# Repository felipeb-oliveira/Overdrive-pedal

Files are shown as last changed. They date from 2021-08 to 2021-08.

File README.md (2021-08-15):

# Overdrive-pedal

## About
A simple overdrive circuit implemented with a OpAmp with soft clipping and a tone control. The OpAmp is configured as a non-inverting amplifier supplied with +9V and GND, with a 4.5V DC bias. The circuit is separated in 5 stages (see schematic image below the 3D model):
  1. Input: one Mono jack for audio;
  2. Equalization: capacitors to filter out some low noise and DC;
  3. Gain stage with soft clipping (made by the 2 opposed diodes on the OpAmp feedback) and low pass filter (capacitor on the OpAmp feedback, and grounded capacitor and resistor on the OpAmp negative input);
  4. Tone Control (Inpired by the Big Muff tone control circuit): basicaly a low pass filter in parallel with a high pass filter, united by a potentiometer to control the filtering.
  5. BJT buffer
  6. Output with volume control: a grounded potentiometer, where the output can be controlled from GND to the total distorced signal.

## Overdrive Schematic
*This is only the soft clipping and tone control circuit, without the inputs, outputs and supply circuits. Please open the Altium project for the full circuit.*

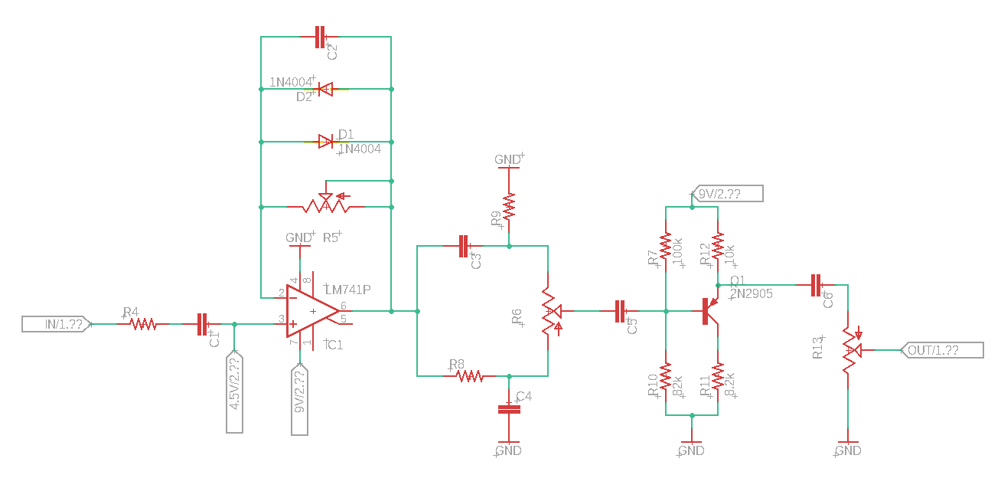
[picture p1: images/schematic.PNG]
Overdrive schematic


## Board
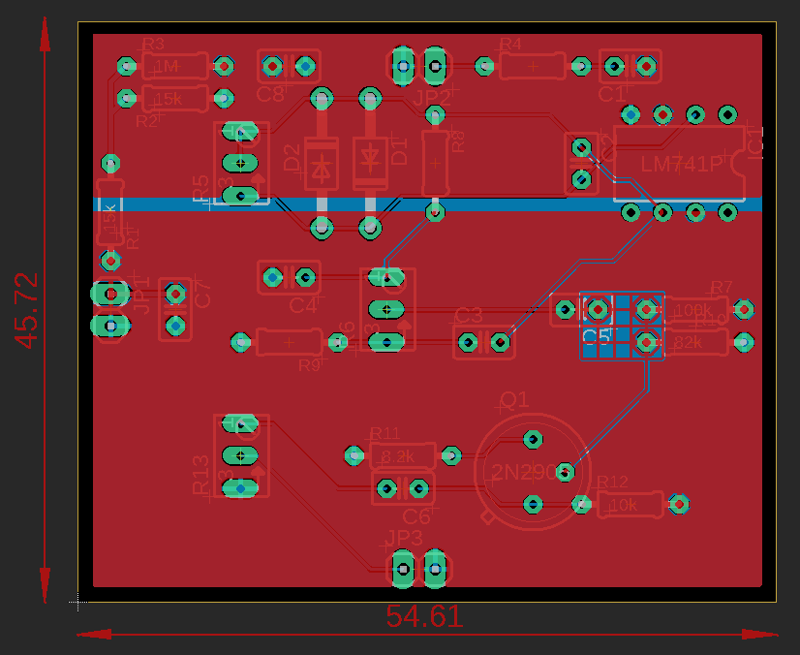
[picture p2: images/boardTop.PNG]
Board top

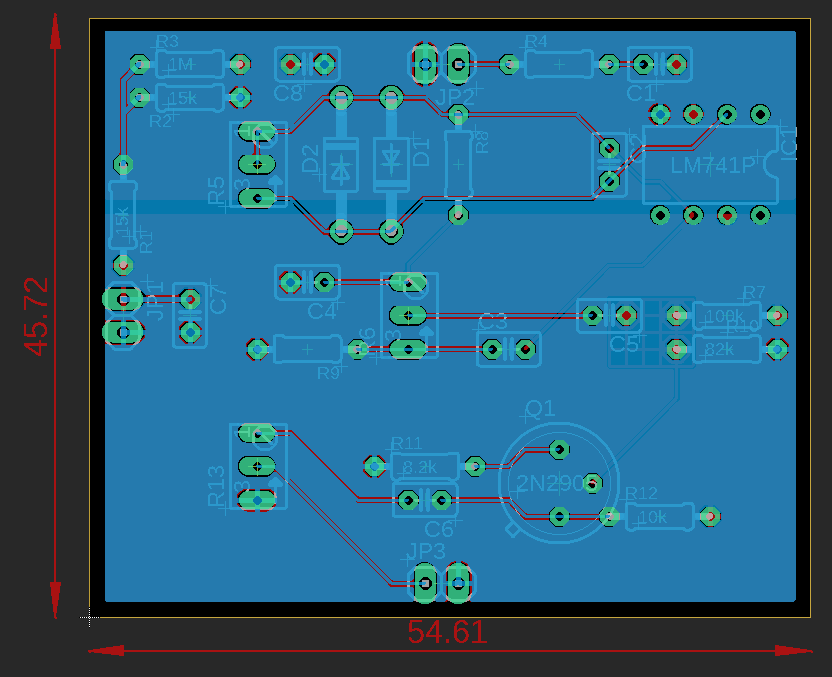
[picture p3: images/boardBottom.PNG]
Board bottom


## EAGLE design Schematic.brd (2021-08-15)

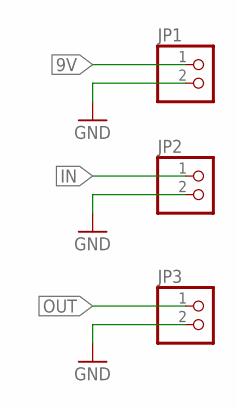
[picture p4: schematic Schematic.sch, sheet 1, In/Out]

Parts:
JP1, JP2, JP3: PINHD-1X2; 1X02

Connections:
9V: JP1.1; also elsewhere on the board
GND: JP1.2, JP2.2, JP3.2; also elsewhere on the board
IN: JP2.1; also elsewhere on the board
OUT: JP3.1; also elsewhere on the board

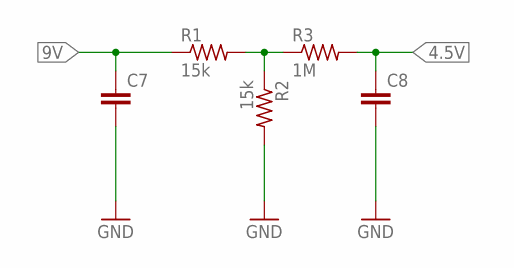
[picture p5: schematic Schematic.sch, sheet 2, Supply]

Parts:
C7, C8: C-EU025-025X050; C025-025X050
R1, R2: 15k; 0204/7
R3: 1M; 0204/7

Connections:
4.5V: C8.1, R3.2; also elsewhere on the board
9V: C7.1, R1.1; also elsewhere on the board
GND: C7.2, C8.2, R2.2; also elsewhere on the board
unnamed: R1.2, R2.1, R3.1

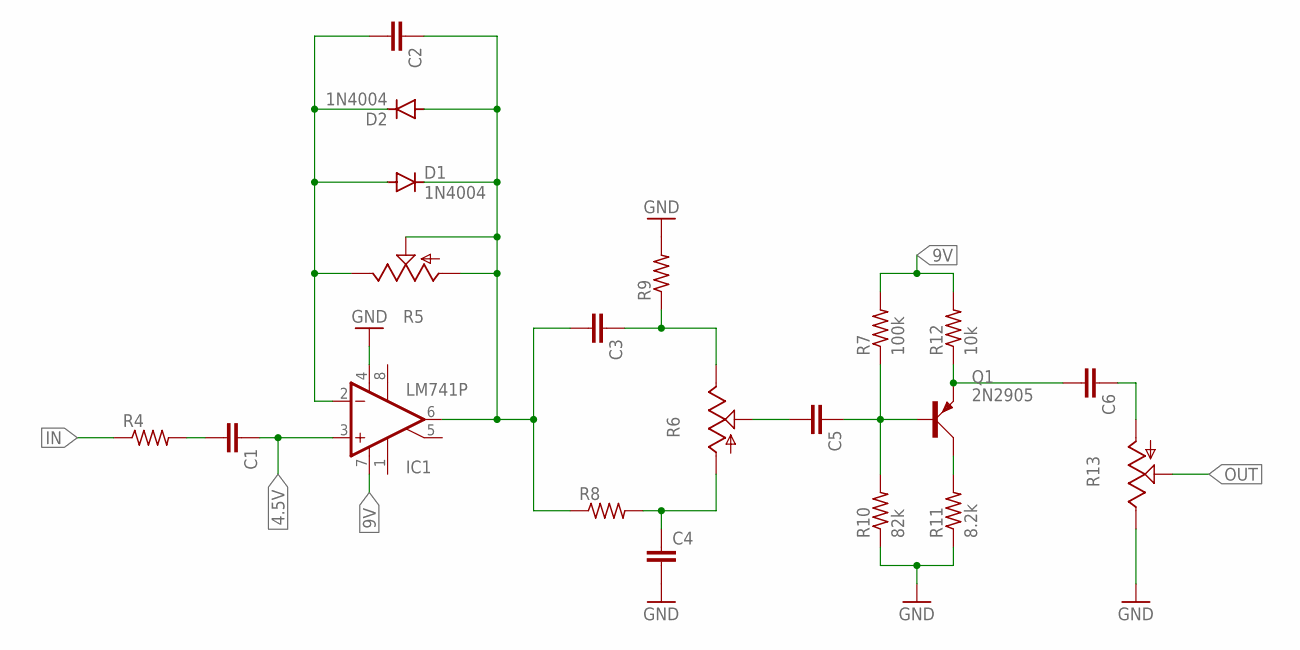
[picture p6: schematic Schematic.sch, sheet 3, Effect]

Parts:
C1, C2, C3, C4, C5, C6: C-EU025-025X050; C025-025X050
D1, D2: 1N4004; DO41-10
IC1: LM741P; DIL08
Q1: 2N2905; TO39
R4, R8, R9: R-US_0204/7; 0204/7
R5, R6, R13: TRIM_US-B64Y; B64Y
R7: 100k; 0204/7
R10: 82k; 0204/7
R11: 8.2k; 0204/7
R12: 10k; 0204/7

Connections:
4.5V: C1.1, IC1.3 (+IN); also elsewhere on the board
9V: IC1.7 (V+), R7.2, R12.2; also elsewhere on the board
GND: C4.2, IC1.4 (V-), R9.2, R10.1, R11.1, R13.E; also elsewhere on the board
IN: R4.1; also elsewhere on the board
unnamed: C1.2, R4.2
unnamed: C2.1, C3.2, D1.C, D2.A, IC1.6 (OUT), R5.A, R5.S, R8.1
unnamed: C2.2, D1.A, D2.C, IC1.2 (-IN), R5.E
unnamed: C3.1, R6.E, R9.1
unnamed: C4.1, R6.A, R8.2
unnamed: C5.2, R6.S
unnamed: C5.1, Q1.2 (B), R7.1, R10.2
unnamed: C6.2, Q1.1 (E), R12.1
unnamed: Q1.3 (C), R11.2
unnamed: C6.1, R13.A
OUT: R13.S; also elsewhere on the board

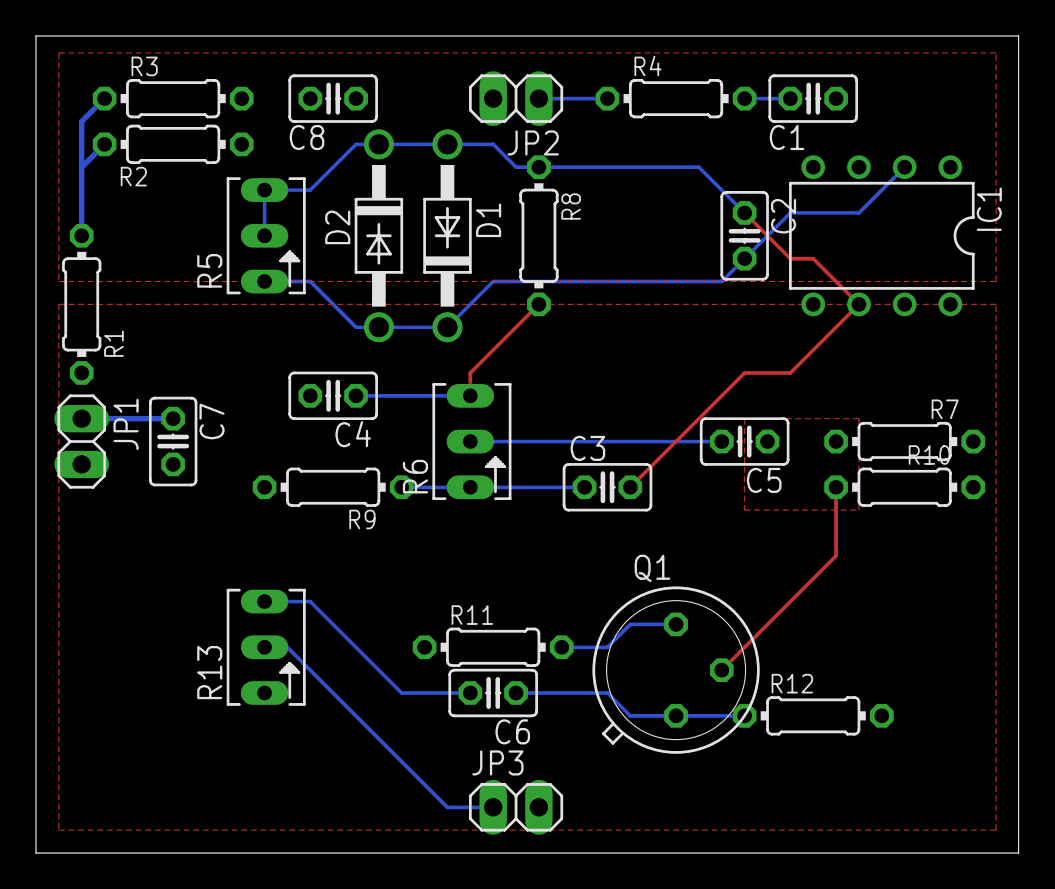
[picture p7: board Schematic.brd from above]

Board: 2 copper layers, 54.6 x 45.4 mm, 28 parts (0 on the bottom side), 16 nets.
